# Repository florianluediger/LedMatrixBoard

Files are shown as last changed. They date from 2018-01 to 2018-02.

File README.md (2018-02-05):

# Led Matrix Board
This is the board layout for a circuit containing two 8x8 LED matrices controlled by some MAX7219 drivers and an ESP8266 microcontroller. It is also possible to cascade multiple boards to get a wider display.

# Required parts
 - [ESP2866 development board](https://www.gearbest.com/transmitters-receivers-module/pp_366523.html?wid=21)
 - [2x MAX27XX LED drivers](https://www.maximintegrated.com/en/products/power/display-power-control/MAX7221.html)
 - [2x 8x8 single color 60.2mm LED matrices with row cathodes and column anodes](https://www.tme.eu/de/details/lmd23088aag-101a/led-matrix-displays/wenrun/lmd23088aag-101a-01/)
 - 2x 10kOhm resistors
 - 1x 200nF ceramic capacitor
 - 1x 4.4uF electrolytic capacitor
 - a power jack
 - some sockets and headers

# Images
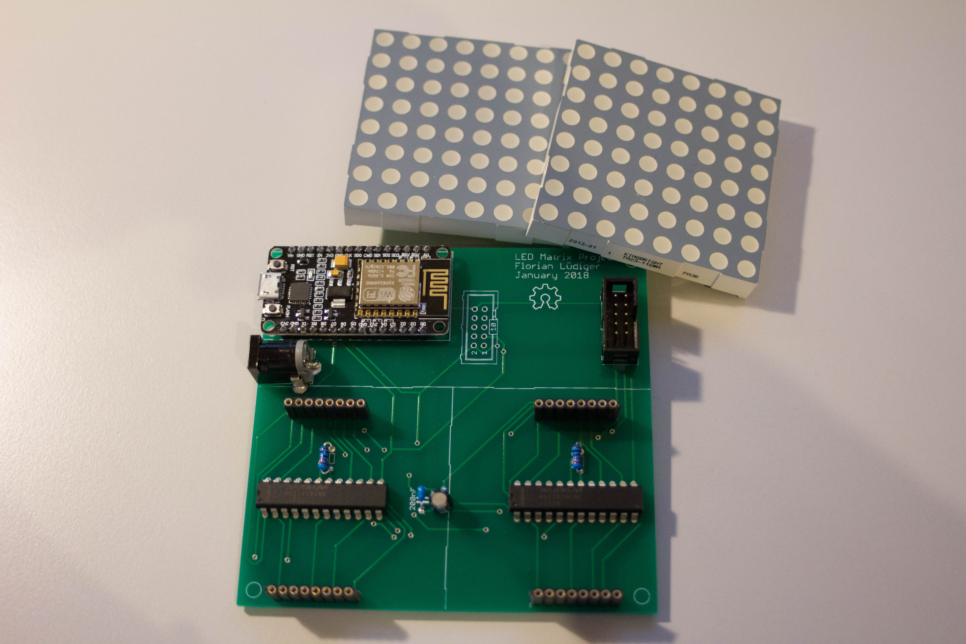
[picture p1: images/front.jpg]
front view Front view


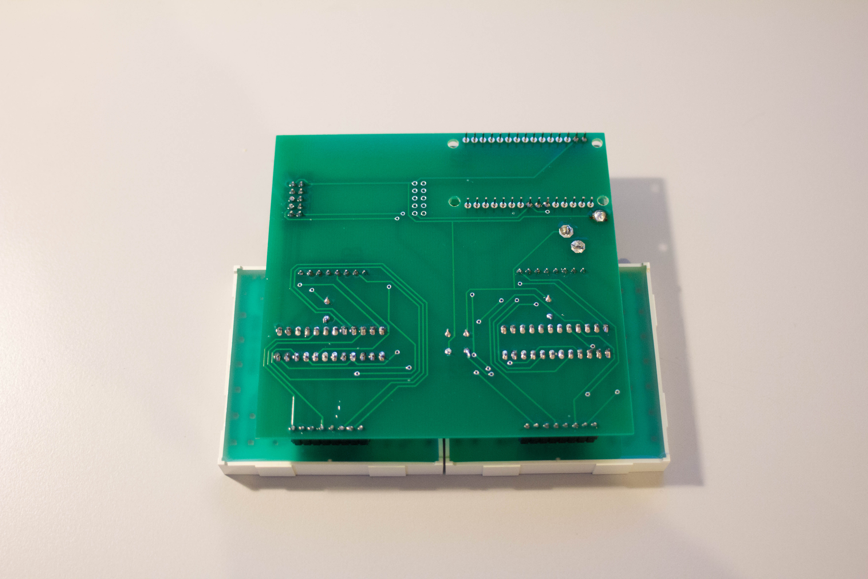
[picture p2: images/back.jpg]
rear view Rear view


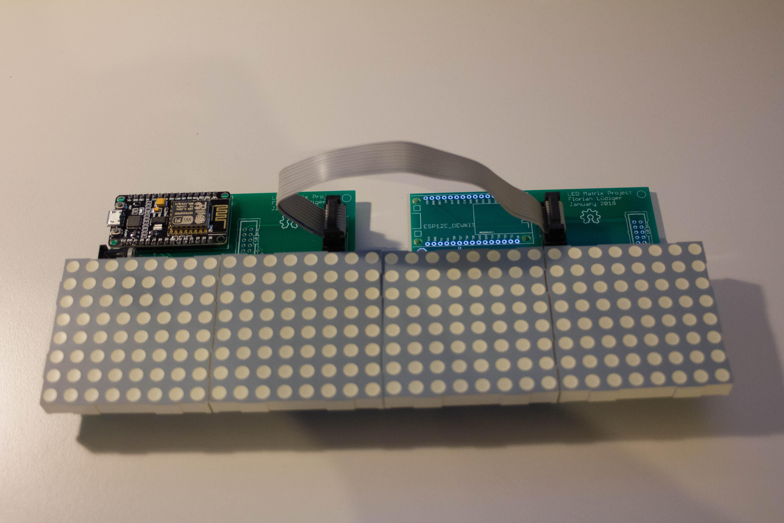
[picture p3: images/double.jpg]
double Two cascaded boards


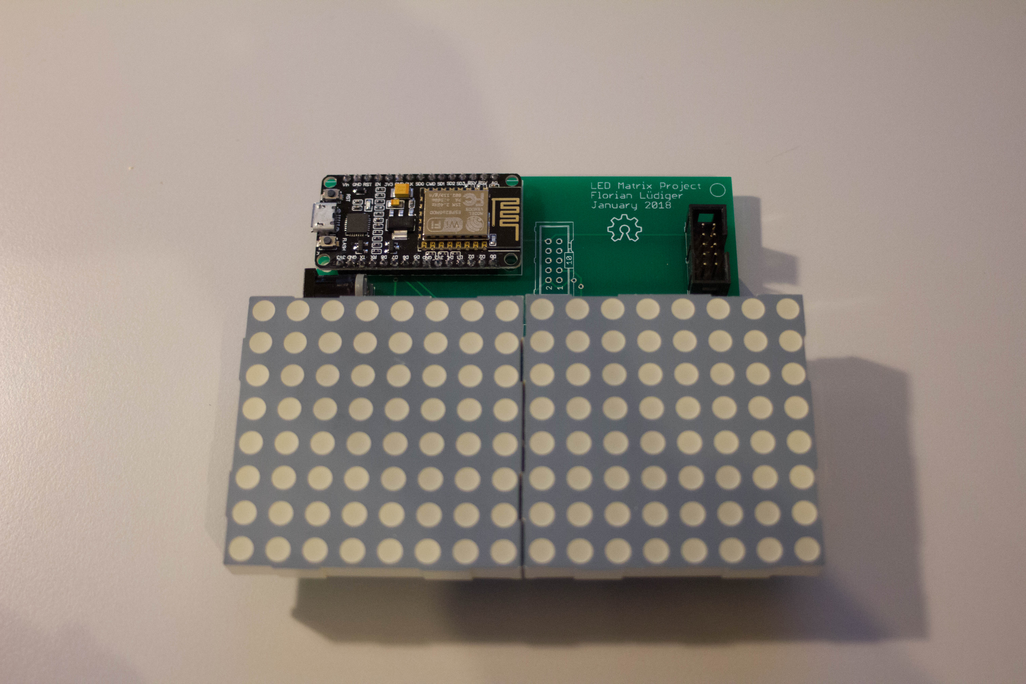
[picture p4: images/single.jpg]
single A single board


# Additional information
 - http://playground.arduino.cc/Main/LEDMatrix

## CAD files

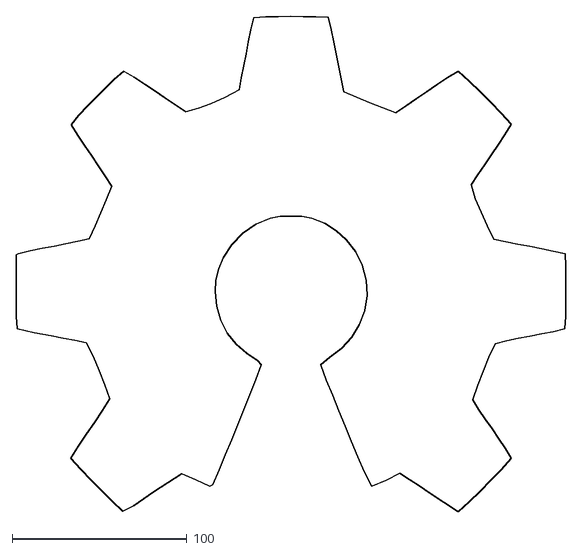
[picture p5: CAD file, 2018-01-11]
oshw-logo.dxf
314.8 x 283.5

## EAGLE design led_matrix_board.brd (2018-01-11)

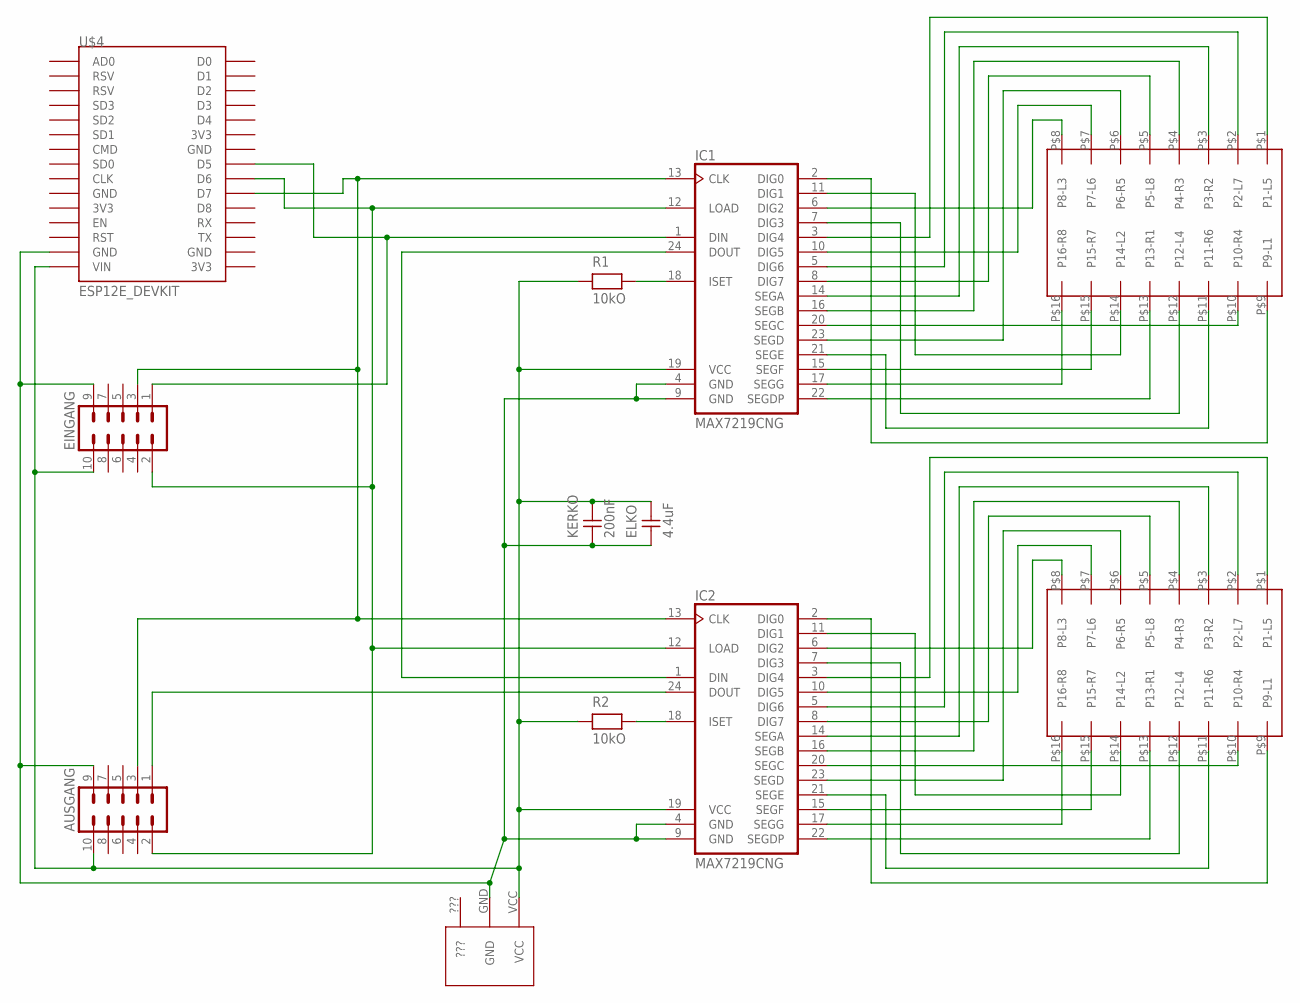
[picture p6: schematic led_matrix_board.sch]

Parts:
AUSGANG: ML10
EINGANG: ML10
ELKO: 4.4uF; C-5
IC1, IC2: MAX7219CNG; DIL24-3
KERKO: 200nF; C-5
R1, R2: 10kO; R-5
U$1, U$2: MATRIX
U$3: LUM1613-18; LUM16113-18
U$4: ESP12E_DEVKIT

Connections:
???: U$3.???
unnamed: IC1.20 (SEGC), U$1.P$10 (P10-R4)
unnamed: IC1.21 (SEGE), U$1.P$11 (P11-R6)
unnamed: IC2.22 (SEGDP), U$2.P$13 (P13-R1)
unnamed: IC2.14 (SEGA), U$2.P$3 (P3-R2)
unnamed: IC2.16 (SEGB), U$2.P$4 (P4-R3)
unnamed: IC2.23 (SEGD), U$2.P$6 (P6-R5)
unnamed: IC1.11 (DIG1), U$1.P$14 (P14-L2)
unnamed: IC2.15 (SEGF), U$2.P$15 (P15-R7)
unnamed: IC1.22 (SEGDP), U$1.P$13 (P13-R1)
unnamed: IC1.6 (DIG2), U$1.P$8 (P8-L3)
unnamed: IC1.7 (DIG3), U$1.P$12 (P12-L4)
unnamed: IC1.14 (SEGA), U$1.P$3 (P3-R2)
unnamed: IC1.16 (SEGB), U$1.P$4 (P4-R3)
unnamed: IC1.2 (DIG0), U$1.P$9 (P9-L1)
unnamed: IC1.23 (SEGD), U$1.P$6 (P6-R5)
unnamed: IC2.17 (SEGG), U$2.P$16 (P16-R8)
unnamed: IC1.15 (SEGF), U$1.P$15 (P15-R7)
unnamed: IC1.17 (SEGG), U$1.P$16 (P16-R8)
unnamed: IC1.3 (DIG4), U$1.P$1 (P1-L5)
unnamed: IC1.10 (DIG5), U$1.P$7 (P7-L6)
unnamed: IC2.11 (DIG1), U$2.P$14 (P14-L2)
unnamed: IC1.5 (DIG6), U$1.P$2 (P2-L7)
unnamed: IC1.8 (DIG7), U$1.P$5 (P5-L8)
unnamed: IC2.6 (DIG2), U$2.P$8 (P8-L3)
unnamed: IC2.7 (DIG3), U$2.P$12 (P12-L4)
unnamed: IC2.3 (DIG4), U$2.P$1 (P1-L5)
unnamed: IC2.10 (DIG5), U$2.P$7 (P7-L6)
unnamed: IC2.5 (DIG6), U$2.P$2 (P2-L7)
unnamed: IC2.8 (DIG7), U$2.P$5 (P5-L8)
unnamed: IC2.21 (SEGE), U$2.P$11 (P11-R6)
unnamed: IC2.20 (SEGC), U$2.P$10 (P10-R4)
unnamed: IC2.2 (DIG0), U$2.P$9 (P9-L1)
unnamed: EINGANG.1, IC1.1 (DIN), U$4.D5
unnamed: AUSGANG.3, EINGANG.3, IC1.13 (CLK), IC2.13 (CLK), U$4.D7
unnamed: IC1.24 (DOUT), IC2.1 (DIN)
unnamed: AUSGANG.2, EINGANG.2, IC1.12 (LOAD), IC2.12 (LOAD), U$4.D6
unnamed: IC1.18 (ISET), R1.2
unnamed: IC2.18 (ISET), R2.2
unnamed: AUSGANG.10, EINGANG.10, ELKO.2, IC1.19 (VCC), IC2.19 (VCC), KERKO.2, R1.1, R2.1, U$3.VCC, U$4.VIN
unnamed: AUSGANG.1, IC2.24 (DOUT)
unnamed: AUSGANG.9, EINGANG.9, ELKO.1, IC1.4 (GND), IC1.9 (GND), IC2.4 (GND), IC2.9 (GND), KERKO.1, U$3.GND, U$4.GND@1 (GND)

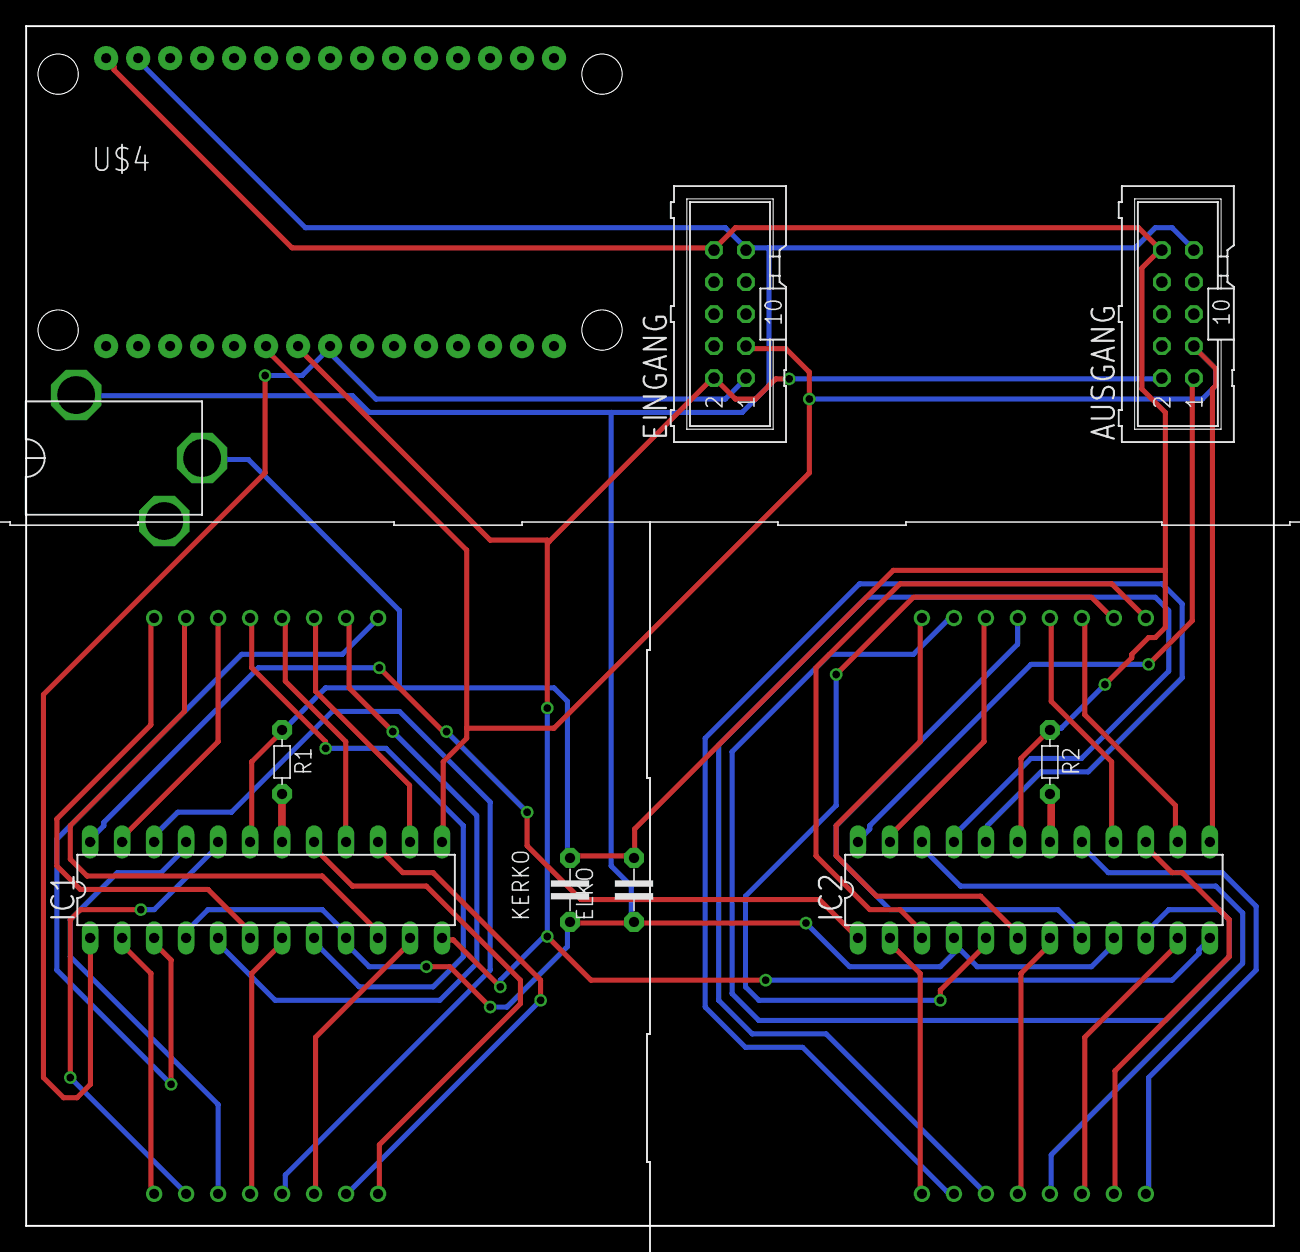
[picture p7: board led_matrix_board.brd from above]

Board: 2 copper layers, 99.1 x 95.2 mm, 12 parts (0 on the bottom side), 41 nets.

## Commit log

2018-01-11 Import Eagle Schematic and Board
    [schaltplan_matrix2.brd, schaltplan_matrix2.sch]
2018-01-11 Import Open Source Hardware Logo
    Use it in eagle like this:
    1. Enter command: run import-dxf
    2. Select the whole image -> Move tool -> Ctrl+Right click drag to desired
    location
    3. Select the Modify tool -> Width -> select desired width -> click on all
    the lines of the image to make them the correct thickness
    [oshw-logo.dxf]
2018-01-11 Add cam file to export the correct gerber files
2018-01-12 Rename Eagle files to English
    [led_matrix_board.brd, led_matrix_board.sch]
2018-01-16 Add Gerber files for etching the board
    [led_matrix_board.GBL, led_matrix_board.GBO, led_matrix_board.GBS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]
2018-02-04 Add some images of the finished board
2018-02-05 Fix wrong link for the LED matrices
